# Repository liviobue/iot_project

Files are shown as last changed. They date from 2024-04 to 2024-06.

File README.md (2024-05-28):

# Information about the Project

## Python-Environment
Python 3.12.1

## Project-Structure
### Electronic:
- PCB-Designs
- Output für die Produktion
- Übersicht über die Board-Tests

### NodeRed
- Alle Flows in NodeRed

### Notebooks
- Jupyter Notebooks mit Prototyp-Code
- Jupyter Notebook mit vereinfachtem Code fürs Elektronik-Testing

### Presentation
- Vor-Präsentation
- Präsentation

### Service
- Information zum Service-File, um die Software automatisch beim Boot des Raspberry Pi's zu starten

### src/iot_project
- Code für die verschiedenen Teile der Software

## Get started manually:
### How to install
Execute this from the Repository-Root
```bash
pip install -e .
```

### How to run the sensor measurement only:
Create `.env`-file with `MONGO_URI` containing the connectionstring to your IoT-Database.
Then, run:
```bash
python -m iot_project.main
```

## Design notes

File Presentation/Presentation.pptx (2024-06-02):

## Gruppe 8 Livio Bürgisser – Noémie Käser – Daniela Komenda

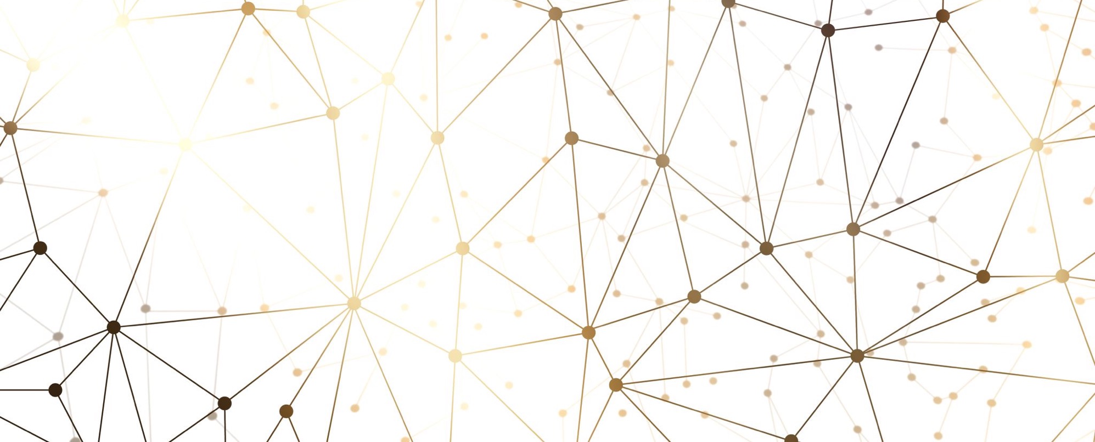
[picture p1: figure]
A web of dots connected

IoT-Projekt

Präsentation
06. Juni 2024

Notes: Herzlich willkommen zu unserer IoT Projekt Präsentation.

## Übersicht

- Problemstellung & Lösung
- Unser Projekt
  - Benutzte Sensoren & Technologien
  - Code
  - Elektronik
  - Dashboard
- Weiterführende Ideen
- Live-Demo

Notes:






Zunächst zum Ablauf der Präsentation.

<klick>
Wir erläutern zunächst die Problemstellung und stellen Euch unsere Lösungsidee vor.

<klick>
Anschliessend werden wir genauer auf unser Projekt eingehen.
Dazu zählt beispielsweise das Vorstellen der benutzten Sensoren und Technologien. Ausserdem werden wir wichtige Code-Überlegungen, sowie unser Vorgehen in Bezug auf die Elektronik vorstellen. Nicht zuletzt präsentieren wir unser Dashboard..

<klick>
Abschliessend werden wir noch einige weiterführende Ideen vorstellen, die leider nicht in scope für dieses Projekt waren.

## Problemstellung

- Luftdichte Räume
- Höhlen
- Tagbau
- Gefahr:
  - Gas-Vergiftung
  - Sauerstoff-Mangel
  - Wird häufig nicht oder zu spät bemerkt

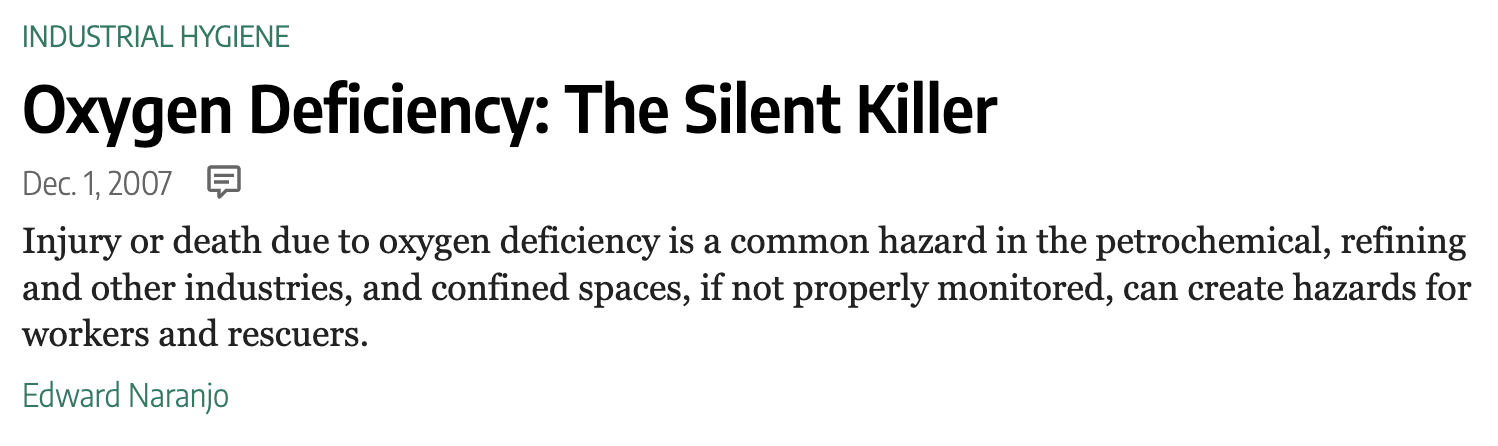
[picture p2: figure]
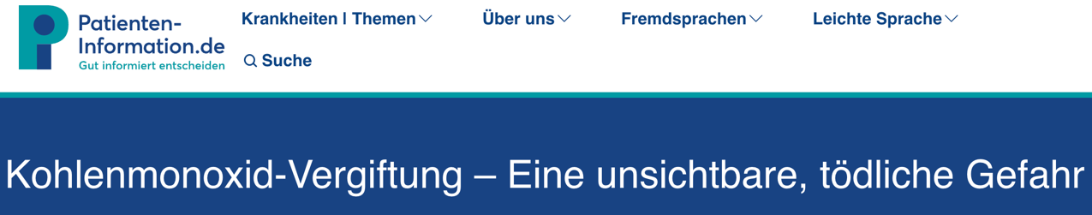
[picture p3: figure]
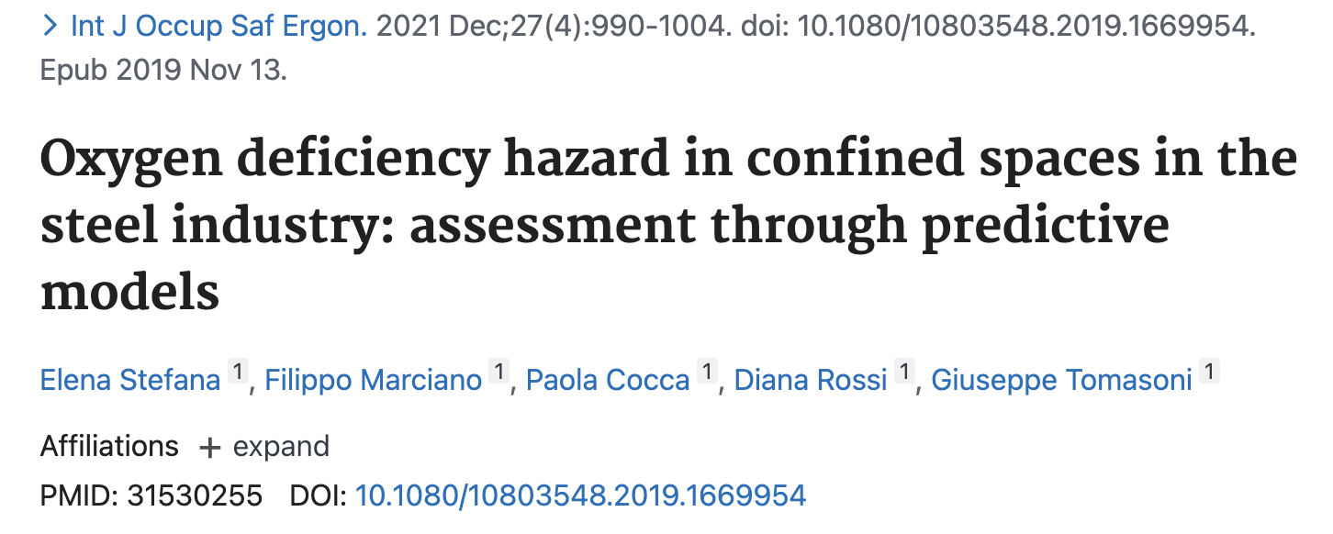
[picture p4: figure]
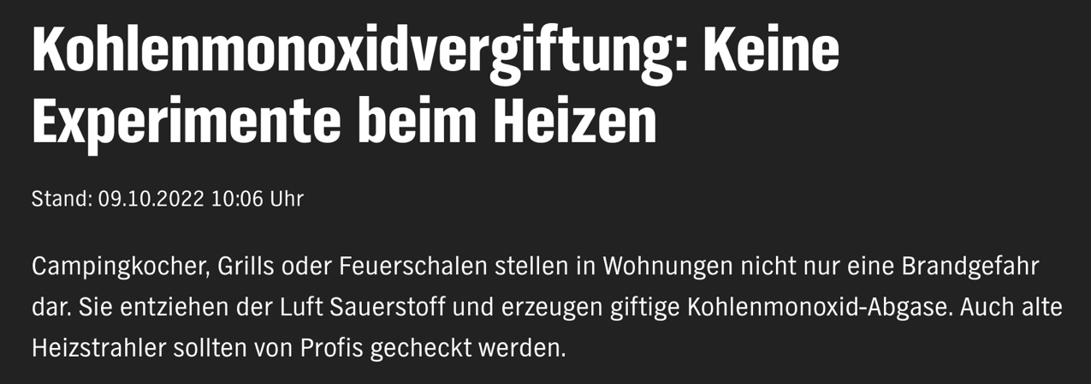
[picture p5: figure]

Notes: Gas kann ein unsichtbarer Feind für uns Menschen sein.
Immer wieder wird in Zeitungen von Unfällen berichtet, in denen Menschen beispielsweise durch zu tiefe Sauerstoff- oder zu hohe Kohlenmonoxid-Werte zu Tode gekommen sind.

<klick>
Insbesondere in luftdichten Räumen, aber beispielsweise auch in Höhlen oder im Tagbau besteht die Gefahr von Gas-Vergiftungen oder einer zu tiefen Sauerstoffkonzentration. Leider werden diese oft erst bemerkt, wenn es bereits zu spät ist und die Menschen das Bewusstsein verloren haben.

## Lösung

- Fahrzeug, das die Umgebung erkundet
- Gas-Konzentrationsmessung im Raum
- Speichern der Gas-Konzentrationen in einer Datenbank für historische Analyse
- Anzeige der Gas-Konzentrationen in einem Dashboard
- Mail bei Gefahr
- Alarm-System bei über- und unterschreiten von Schwellenwerten

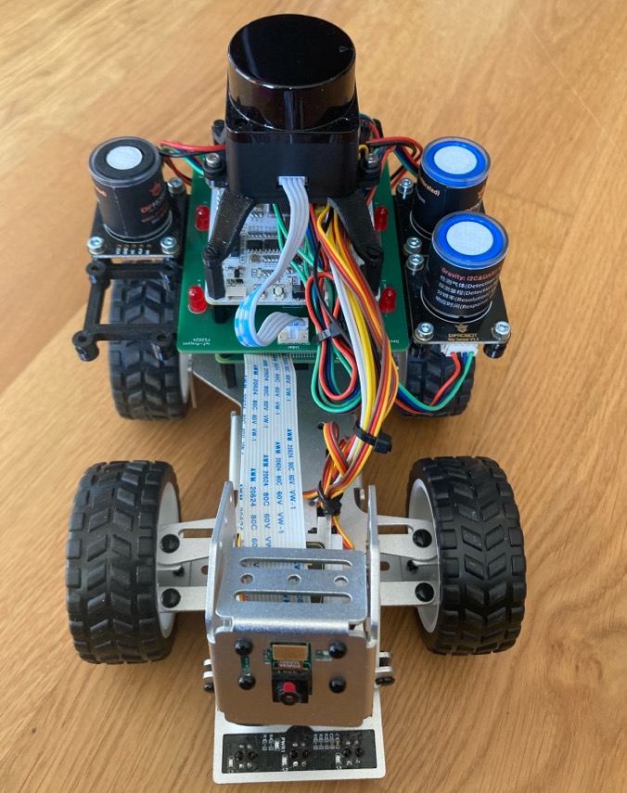
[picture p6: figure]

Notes: Daher stellen wir heute gerne eine mögliche Lösung vor:

<klick>
Unser kleines Fahrzeug kann genutzt werden, um die Umgebung zu erkunden

<klick>
und dabei kontinuierlich die Gas-Konzentration in der näheren Umgebung zu messen.

<klick>
Die Gas-Konzentration wird dann in einer Datenbank gespeichert, so dass man diese auch analysieren könnte, um beispielsweise zu sehen, bei welchen Arbeiten welche Gefahren entstehen könnten.

<klick>
Die Gas-Konzentration wird aber auch in einem Dashboard angezeigt, so dass sie nahezu real-time überwacht werden kann

<klick>
und bei einer Gefahr, wird eine Mail an die Mitarbeitenden geschickt.

<klick>
Das Fahrzeug selber verfügt ebenfalls über ein Alarmsystem, so dass die jeweiligen LED rot leuchten, wenn der betreffende Sensor den definierten Schwellenwert über- beziehungsweise unterschreitet. Ausserdem erzeugt ein Buzzer auch ein akustisches Signal.

## Benutzte Sensoren / Technologie

- Raspberry Pi
- PiCar von Sunfounder
- Gas-Sensoren von DFRobot (vorkalibriert)
  - NH3
  - CO
  - O2
- NodeRed
- Lidar von LDRobot

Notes: Um unsere Lösungen umzusetzen haben wir folgende Sensoren und Technologien genutzt.

<klick>
Zum einen läuft die Software-Lösung auf einem Raspberry Pi.

<klick>
Dieses haben wir an den PiCar von Sunfounder angeschlossen, mit dem wir die Umgebung erkunden können.

<klick>
Als Gas-Sensoren nutzen wir vorkalibrierte Sensoren von DFRobot.

<klick>
Wir haben uns für die Demonstration für Ammoniak-, Kohlenmonoxid- und Sauerstoff-Messung entschieden. DFRobot hat aber noch weitere Sensoren und man kann diese recht einfach ersetzen. Auch in der Software müssten nur wenige Anpassungen vorgenommen werden.

<klick>
Für das Dashboard verwenden wir NodeRed, da wir diese Technologie im Rahmen des Moduls kennengelernt haben und es uns überzeugt hat.

<klick>
Für die Orientierung im Raum haben wir noch einen 2D-Lidar von LDRobot in die Lösung eingebaut, aber leider war die sinnvolle Nutzung von diesem dann Out-of-Scope.

## High-Level Übersicht

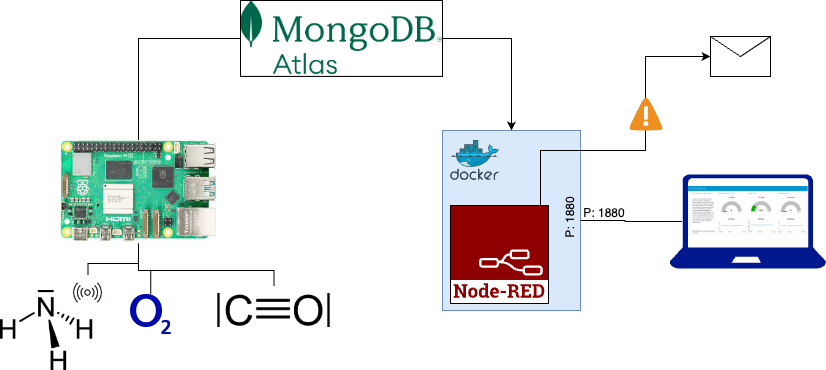
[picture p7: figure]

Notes: Prototypisieren mit Notebooks, nachher umschrieben zur Python-Library.

Python Scripts werden mit Systemd Service auf Raspberry Pi gestartet und der die Software mit Sensor-Messung & PiCar-Steuerung automatisch laufen lässt.

## Code – Externe Libraries

- Sensor-Library von DFRobot
  - Problem: viele Fehler
  - Folge: bricht immer wieder ab
  - Lösung: Library clonen und umschreiben
- Controller PiCar von Sunfounder
  - SunFounder-Library
  - Umschreiben von einigen Funktionen

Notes: Nun erläutern wir gerne noch die wichtigsten Überlegungen zum Software-Code.

<klick>
Um die Sensoren zu nutzen, braucht es die Library von DFRobot. Leider haben wir feststellen müssen, dass es extrem viele Fehler gibt, die das Programm dann abbrechen lassen. Da es sich bei den Sensoren um Hardware handelt, ist es möglich, dass einige Messungen nicht immer funktionieren. Diese sollten dann einfach übersprungen werden und nicht das ganze Programm abbrechen. Daher haben wir uns entschieden, die Library zu klonen und für unser Projekt anzupassen. So konnten wir nur den Teil aus der Library rausnehmen, den wir gebraucht haben.

<klick>
Für den PiCar haben wir die Library von SunFounder verwendet und dort beim picarx-controller einige Funktionen angepasst, so dass der PiCar beispielsweise vor einer Wand langsamer wird, damit man nicht mit vollem Tempo hineinfährt.

## Code – Datenverarbeitung

- Measurement-Loop:
  - Messung im Measurement-Intervall von 0.1 Sekunden
  - Alert-Überprüfung
  - Aggregation der Werte über 0.5 Sekunden (Min, Max, Avg)
  - MongoDB
    - Datenbereinigung?

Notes: Für die Datenverarbeitung haben wir einen Measurement-Loop erstellt, der alle 0.1 Sekunden die Sensoren ansteuert und die Gas-Konzetration misst.

Die Werte werden nach diesem Measurement-Intervall überprüft und mit den festgelegten Alert-Level verglichen.


Die gelesenen Daten werden in einer Liste gespeichert und alle 0.5 Sekunden aggregiert. Dabei wird der Timestamp übergeben, sowie der Minimal- und Maximal- und der Durchschnittswert berechnet.

Die aggregierten Daten werden dann in die MongoDB geladen.

Für die Zukunft müsste man sich allenfalls noch ein Handling überlegen, wie man mit älteren Daten umgeht. Allenfalls könnte man Tages-Durchschnitte berechnen und in eine separate Collection speichern und alte Raw-Daten dann löschen, damit die Datenbank nicht überflutet wird.

## Code – Alarm

- AlertManager:
  - Setup-Verwaltung
  - Überprüfung ob Schwellenwerte über- beziehungsweise unterschritten wurden
- Modi:

| NORMAL | ALERT | ACKNOWLEDGE
Grüne LED | Leuchtend | Aus | Aus
Rote LED(s) | Aus | Blinkend | Leuchtend
Buzzer | Aus | An | Aus

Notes: Ein wichtiger Teil des Codes ist auch der AlertManager. Dieser verwaltet den Setup, wo die Adressierung der Elektronik-Komponenten festgelegt wird. Ausserdem werden im AlertManager die Schwellenwerte definiert und überprüft, ob sie über- beziehungsweise unterschritten werden.

<klick>
Für den Alarm haben wir 3 unterschiedliche Modi definiert.

Der erste Modus ist der normale Modus. Dabei leuchtet die grüne LED und die roten LEDs und der Buzzer sind ausgeschaltet. So weiss man, dass das Gerät an ist und die Software läuft.
Bei einem Alarm, wird die grüne LED ausgeschaltet und die betreffenden roten LEDs blinken. Auch der Buzzer ist dann an. Bei einem Alarm hat man die Möglichkeit, den Switch zu drücken, so dass der Zustand in den Acknowledge-Modus wechselt. In diesem ist die grüne LED immer noch aus und die betreffenden roten LEDs leuchten statt zu blinken. Ausserdem ist der Buzzer wieder ausgeschaltet. Alle 0.4 Sekunden wird überprüft, ob sich die Gas-Konzentration immer noch im kritischen Bereich befindet. Falls nicht, wird wieder auf den Normal-Modus zurückgesetzt.

## Elektronik – Breadboard-Prototyping

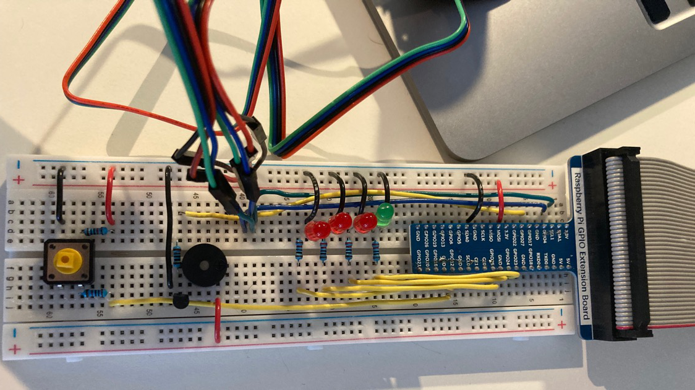
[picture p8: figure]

- 1. Prototyp nur mit O2-Sensor
- 2. Prototyp mit NH3-, CO- und O2-Sensor, aber ohne Buzzer und Switch
- 3. Prototyp mit allen Sensoren, inklusive Buzzer und Switch

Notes: Nun kommen wir zur Elektronik.
Ursprünglich haben wir die Prototypisierung mit einem Breadboard gemacht.

<klick>
In der ersten Iteration haben wir nur einen Sensor angeschlossen und auch dementsprechend nur 1 rotes und 1 grünes LED.

<klick>
In der 2. Iteration haben wir dann alle drei Sensoren genutzt und überprüft, ob die LEDs einzeln leuchten aber ob es auch möglich ist, dass mehrere gleichzeitig Alarm anzeigen.

<klick>
In der 3. und letzten Iteration haben wir dann alle Sensoren und auch den Buzzer und den Switch angeschlossen.

Doch obwohl wir versucht haben, die Kabel so kurz wie möglich zu halten, waren wir mit dieser klobigen Lösung unzufrieden. Daher haben wir uns entschieden, unsere eigene Platine zu designen.

## Elektronik – Platinen-Design

- Schwierigkeit
  - Platine soll Erweiterung mit PiCar und Lidar ermöglichen
  - Nicht alle Pins können genutzt werden
  - Theoretisch können 4 Sensoren parallel geschaltet werden
- Lösung
  - Dokumentation von PiCar, welche Pins genutzt werden
  - Dokumentation von Lidar, welche Pins genutzt werden
- Umsetzung
  - Pins werden entsprechend angeschrieben
  - Platz für 4 Sensoren schaffen

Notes: Die Schwierigkeit war, dass wir eigentlich nur die 3 Gas-Sensoren, nicht aber den Lidar und den PiCar auf dem Board testen konnten. Daher wussten wir, dass wir nicht alle Pins nutzen dürfen, da wir die Erweiterung mit dem PiCar und dem Lidar unbedingt offenbehalten wollten. Ausserdem kann man theoretisch 4 Sensoren von DFRobot parallel nutzen, daher wollten wir auch einen 4. Sensor im Elektronik-Design einbinden.

<klick>
Die Lösung für die Schwierigkeiten war, dass wir die Dokumentation vom PiCar und vom Lidar nutzen mussten, um zu erfahren, welche Pins gebraucht werden. Glücklicherweise gab es beim PiCar und beim Lidar keine Überschneidungen.

<klick>
Als wir die Pins auf dem Design entsprechend angeschrieben und blockiert hatten, haben wir für die restlichen 4 Sensoren die Pins verteilt

## Elektronik – Platinen-Design mit KiCAD

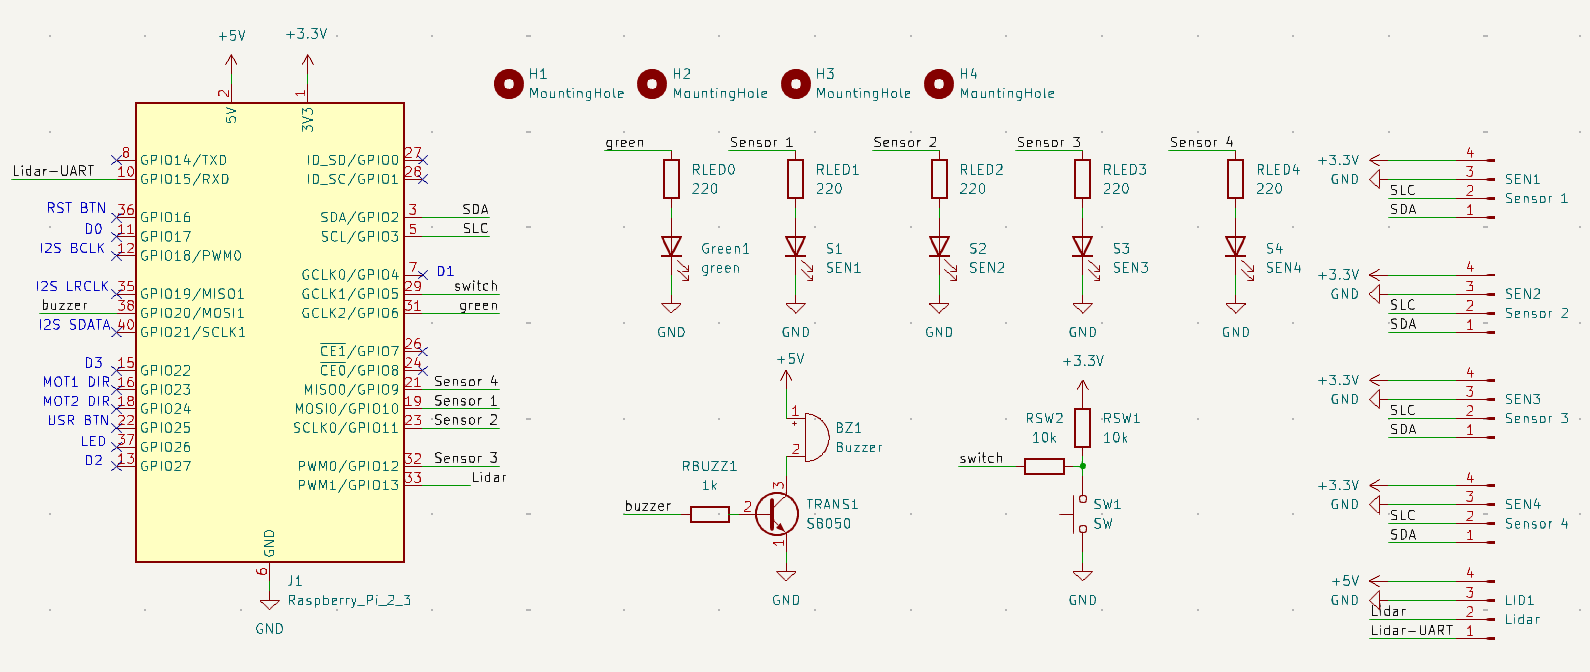
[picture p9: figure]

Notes: Dies hat dann so ausgesehen.
Das Design wurde mit KiCAD erstellt. Im Schemata-Editor kann man alle Komponenten zeichnen und dem Board zuordnen. Verbindungen werden dann erst im nächsten Schritt gemacht.

## Elektronik – Platinen-Design

- Verbindungen
  - 2 Layer, da günstig und das Design genügend einfach
- Herausforderung
  - Komponenten-Footprint muss stimmen
  - Holes müssen am korrekten Ort sein
  - Pins müssen am korrekten Ort sein
  - Komponenten, die höher sind, dürfen nicht mit dem Board vom PiCar kollidieren

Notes: Nachdem das Design fertiggestellt war, konnte man im PCB-Editor das eigentliche Design erstellen. Wir haben beschlossen, dass wir uns auf 2 Layer beschränken, da wir grundsätzlich einen einfachen Use-Case haben und 2 Layer deutlich günstiger sind.

<klick>
Die Herausforderung war, dass wir überprüfen mussten, dass die gewählten Footprints stimmen, damit wir die richtige Grösse der Komponenten haben. Ausserdem mussten wir genau messen, um die Schraub-Löcher und die Pins am richtigen Ort zu haben.
Da wir das Board vom PiCar auf unser Design raufstecken wollten, mussten wir auch sicherstellen, dass höhere Komponenten, wie beispielsweise der Transistor oder der Buzzer nicht mit der Elektronik des PiCar-Boards kollidieren.

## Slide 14

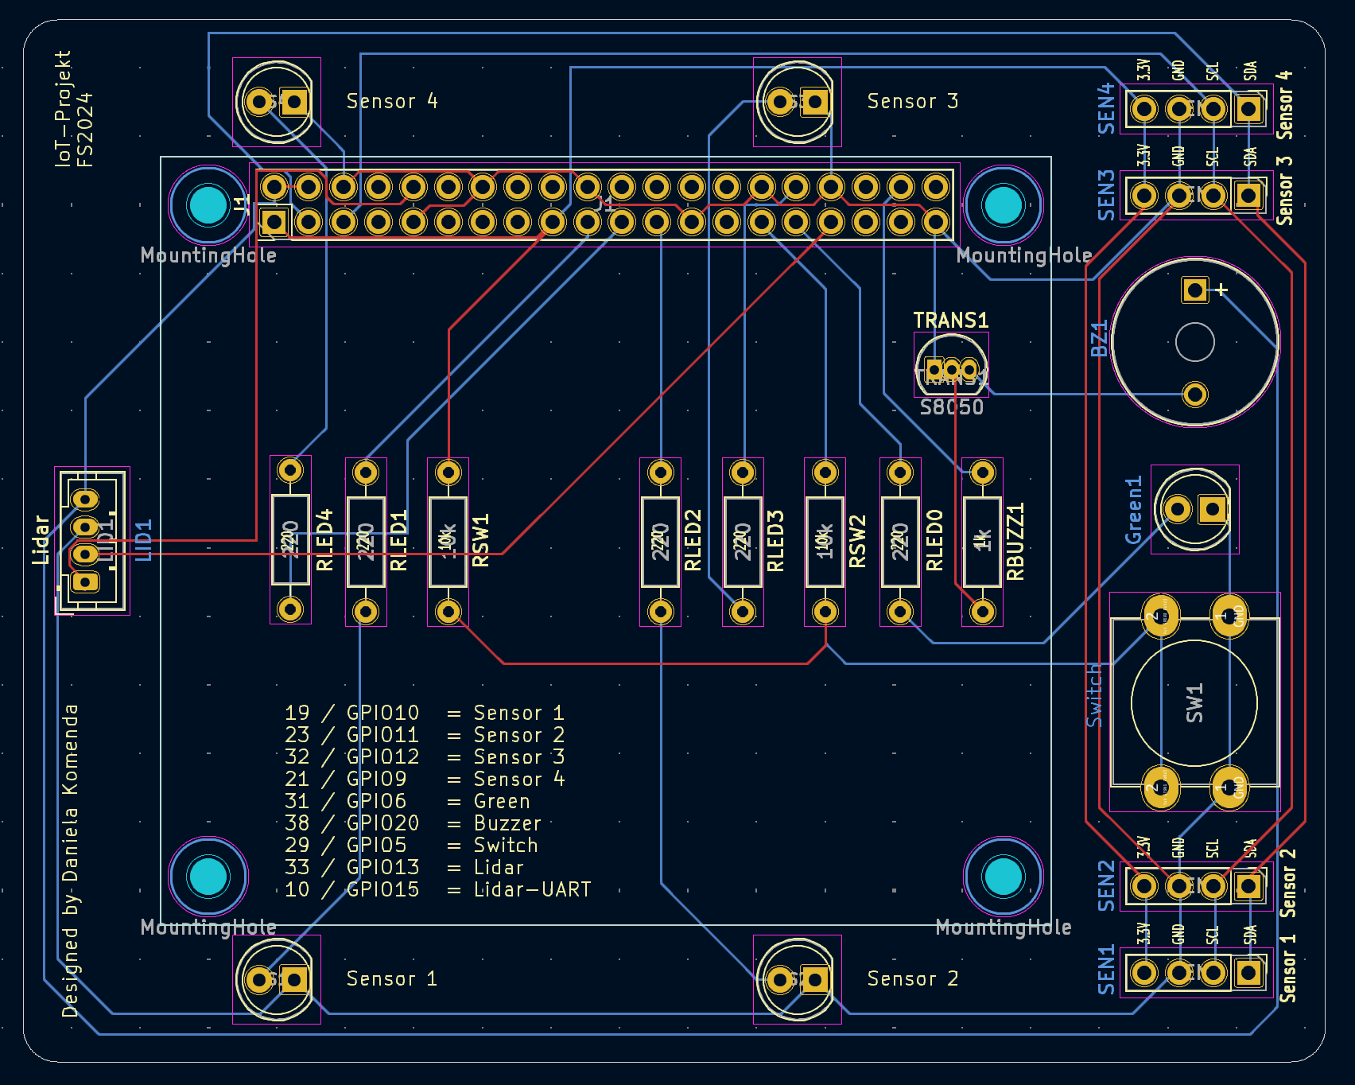
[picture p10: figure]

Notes: Die Lösung sah am Schluss so aus.

## Elektronik – Produktion durch PCB-Way

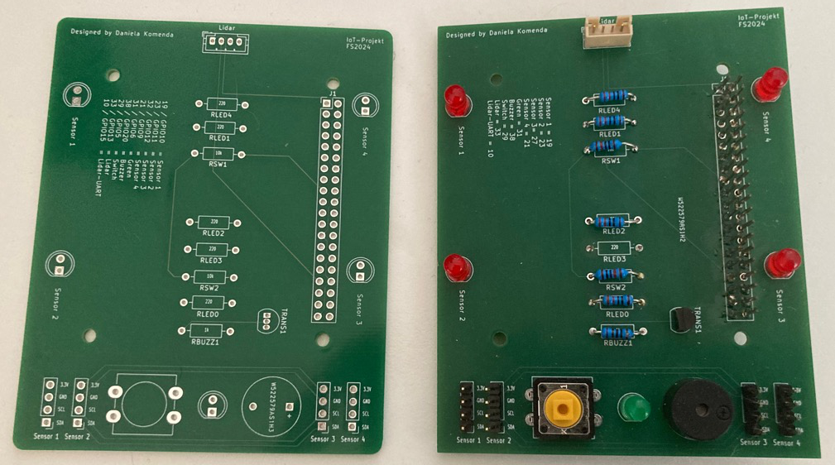
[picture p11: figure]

- Produktion von 10 PCB durch PCB-Way in China
- Bestellung der Komponenten bei DigiKey
- Selbstständiges Löten der Komponenten

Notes: Als das Design dann fertig war, haben wir uns informiert, wo man es bestellen kann.

<klick>
Anschliessend haben wir 10 PCBs bei PCB-Way in China bestellt.

<klick>
Die Elektronik-Komponenten haben wir bei DigiKey bestellt.

<klick>
Und anschliessend auf die Boards gelötet.

## Elektronik – Löten

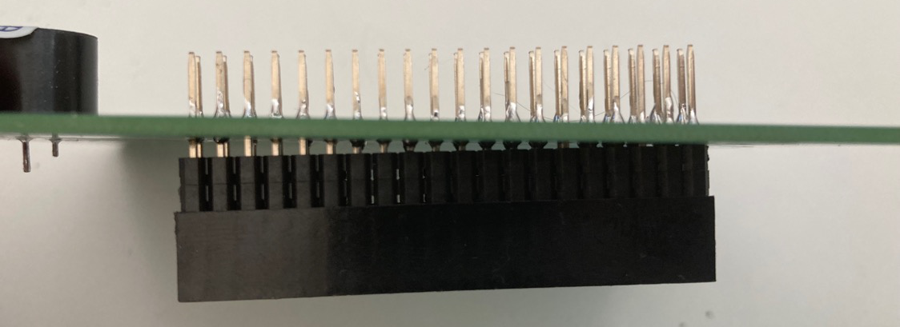
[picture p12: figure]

- Herausforderung 1:
  - Komponenten sollen nicht schräg gelötet sein
- Lösung 1:
  - Tape
- Herausforderung 2:
  - Löt-Zinn mit Blei
- Lösung 2:
  - siehe Bild

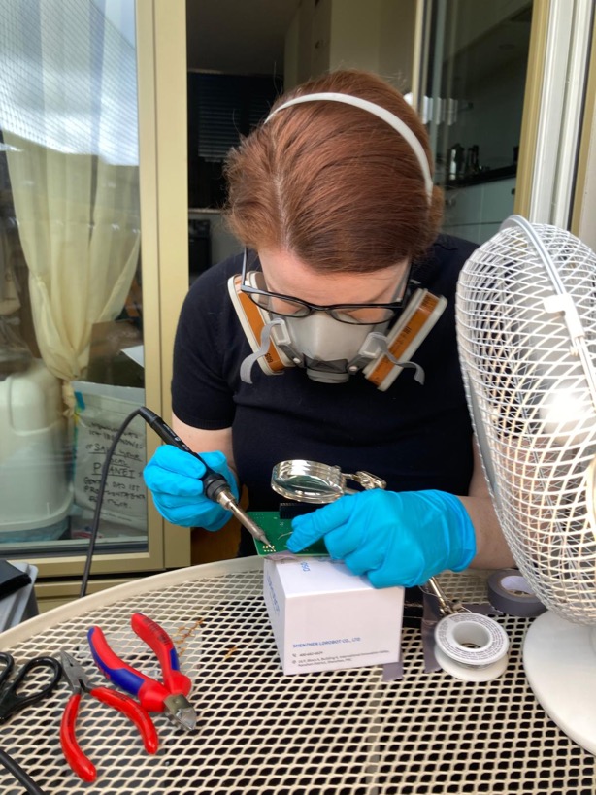
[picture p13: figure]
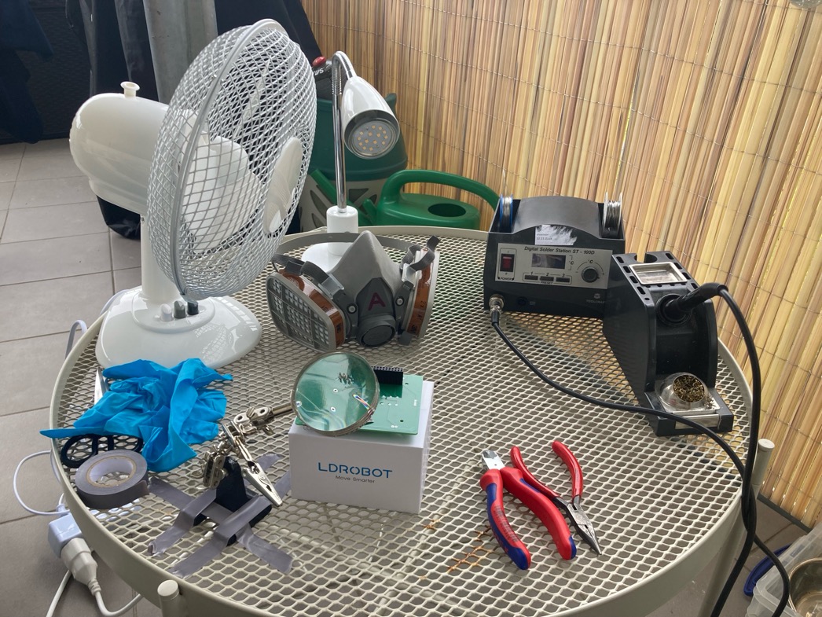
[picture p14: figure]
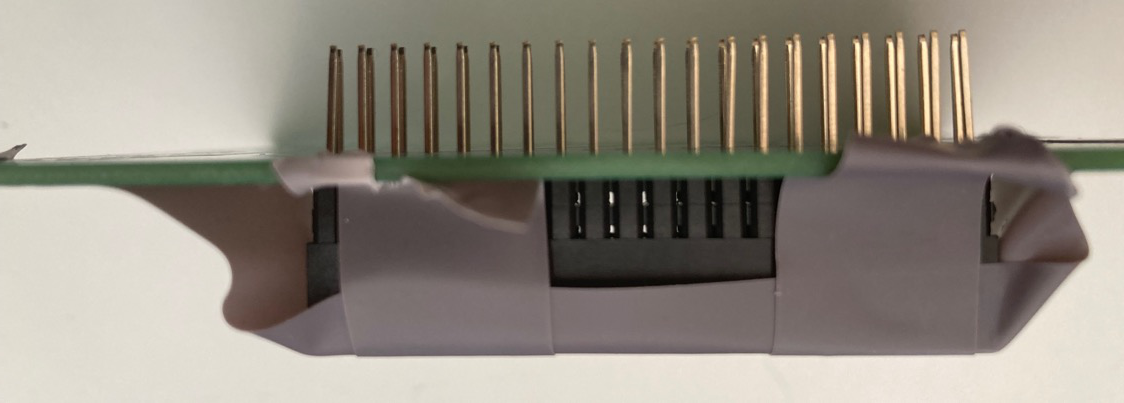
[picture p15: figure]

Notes: Beim Löten kamen wir an folgende Herausforderungen:

<klick>
Beim ersten Lötversuch stellten wir fest, dass die Komponenten durchaus auch schräg gelötet werden können, wie man auf dem Bild sieht.

<klick>
Als Lösung dafür haben wir Tape genutzt, um die Komponenten zu befestigen.

<klick>
Die zweite Herausforderung war, dass wir hauptsächlich mit bleihaltigem Löt-Zinn gearbeitet haben, da dieser insbesondere für schwierigere Lötstellen, wie die Pins oder die Löt-Stellen des Transistors geeigneter war als bleifreier Löt-Zinn. Da er aber giftig ist, mussten wir uns eine Lösung überlegen.

<klick>
Daher wurde auf meinem Balkon eine gut durchlüftete Löt-Station eingerichtet und als zusätzlicher Schutz noch eine Brille und eine Atemschutz-Maske verwendet.

## Dashboard mit Node Red

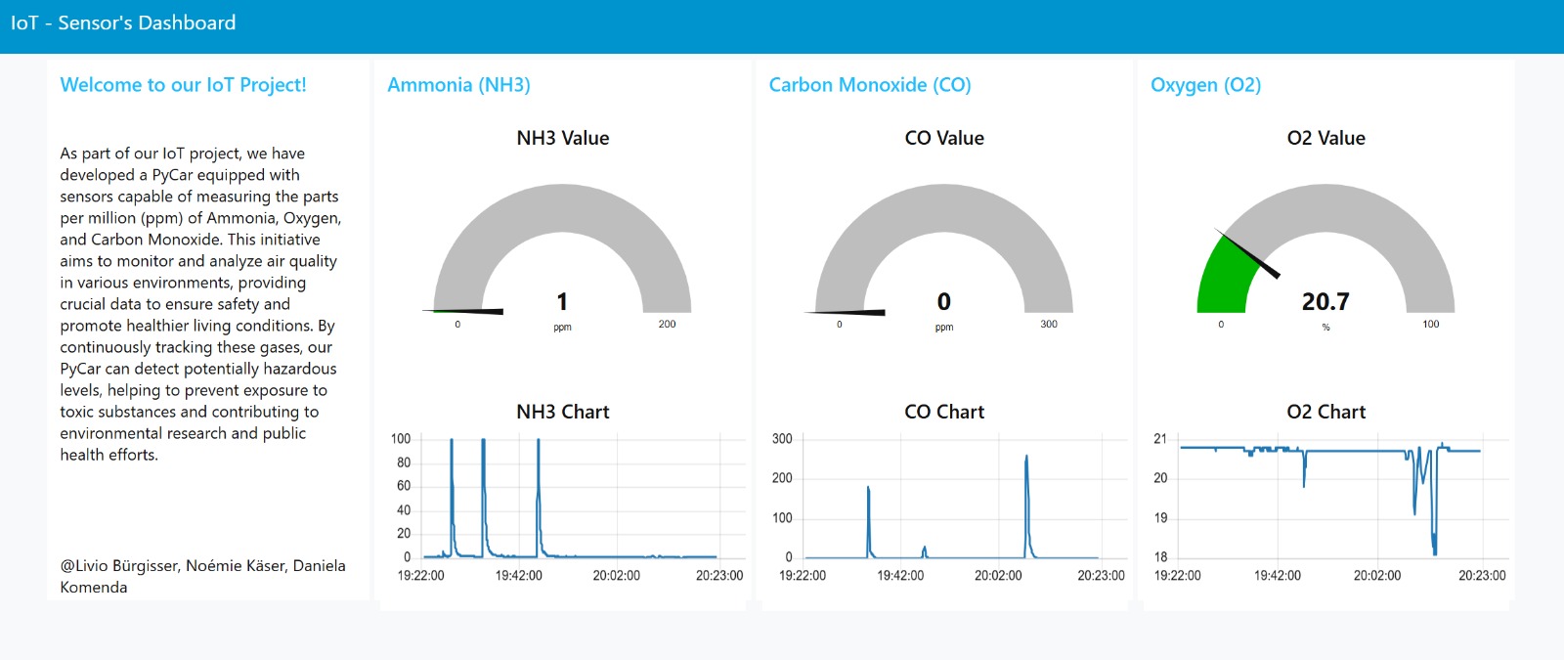
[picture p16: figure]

## Node ReD FLOW

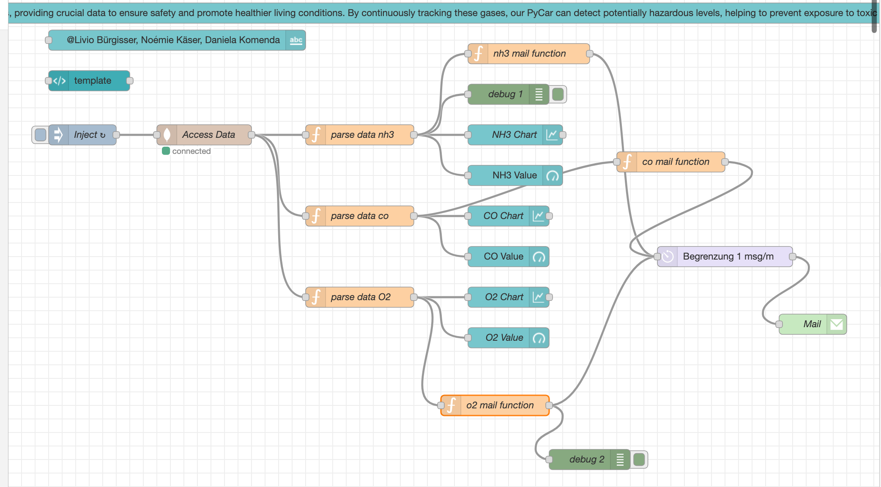
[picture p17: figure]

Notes: Hier flow für dashboard gerade verbunden mit einem mail, welches bei gefahr versendet wird.

## Weiterführende Ideen

- Raum-Erfassung mit Lidar und PiCar-Kamera
- Finden des Gas-Lecks
- Energie-Management des Fahrzeugs
- Daten-Management

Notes: Nun kommen wir noch zu den Ideen, die leider Out-of-Scope waren.

<klick>
Zum einen hätte man den PiCar selbstständig den Raum erkunden lassen können. Dazu hätte man den Lidar-Sensor für die Raum-Erfassung nutzen können, damit der PiCar gezielter den Raum erkundet.

<klick>
Ausserdem wäre es cool gewesen, wenn der PiCar bei einer auffälligen Gas-Konzentration, versucht hätte, herauszufinden, woher das Gas kommt und sich dann immer näher zum Gas-Leck bewegt hätte.

<klick>
Ausserdem hält der Akku des PiCars nicht sehr lange, daher wäre es sicherlich noch sinnvoll, sich in Zukunft Gedanken zum Energie-Management des Fahrzeugs zu machen. Allenfalls könnte man noch weitere Batterien anschliessen oder allenfalls einen Arduino statt eines Raspberry Pis verwenden.

<klick>
Das Daten-Management in der DB haben wir ja bereits angesprochen. Es würde auch dort noch weitere Optimierungen geben.

## Live-Demo

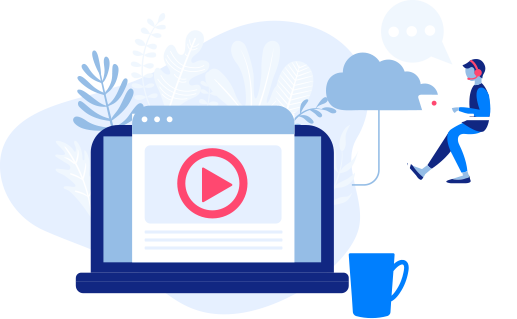
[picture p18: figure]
Request a demo - Comsys

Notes: Damit sind wir am Ende unserer Präsentation und würden nun gerne eine Live-Demo unserer IoT-Lösung demonstrieren.
Wir haben dafür ein Video aufgenommen, dass den gesamten Scope zeigt.
Für die Vorführung im Klassenzimmer haben wir uns überlegt, dass wir einfach kurz die Fahrweise, sowie den O2-Sensor und unser Dashboard demonstrieren.
Wir hätten aber auch Räucherstäbchen und Ammoniak dabei, würden aber empfehlen, dass wir dieses nicht im Unterrichtraum selber demonstrieren, da es für die nächste Gruppe und Euch als Dozierende eventuell unangenehm werden könnte.

## Github-Repo

https://github.com/liviobue/iot_project

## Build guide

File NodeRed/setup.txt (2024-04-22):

sudo apt-get update
sudo apt-get full-upgrade

sudo apt install sense-hat 
sudo reboot

sudo apt install python3-paho-mqtt

# Prüfen ob installiert
node --version
npm --version

bash <(curl -sL https://raw.githubusercontent.com/node-red/linux-installers/master/deb/update-nodejs-and-nodered)

sudo apt install python3-wget

# start, stop node red
node-red-start
node-red-stop

# mosquitto
sudo apt install mosquitto
sudo apt install mosquitto-clients

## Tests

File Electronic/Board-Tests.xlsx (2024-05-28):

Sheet: Daniela
Daniela | Test 1 small | Test 2 big | Nachtest | TEST
LED Green | pass | pass | - | OK
LED 1 | pass | - | - | OK
LED 2 | pass | - | - | OK
LED 3 | pass | - | - | OK
LED 4 | pass | - | - | OK
Switch | pass | - | - | OK
Buzzer | pass | - | - | OK
Sensor 1 | pass | pass | - | OK
Sensor 2 | pass | pass | - | OK
Sensor 3 | pass | pass | - | OK
Sensor 4 | pass | - | - | OK
Lidar | - | pass | - | OK
PiCar | - | pass | - | OK

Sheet: Noémie
Noémie | Test 1 small | Test 2 big | Nachtest | TEST
LED Green | pass | pass | pass | OK
LED 1 | pass | - | - | OK
LED 2 | pass | - | - | OK
LED 3 | pass | - | - | OK
LED 4 | pass | - | - | OK
Switch | pass | - | - | OK
Buzzer |  |  | pass | OK
Sensor 1 | pass | pass | pass | OK
Sensor 2 | pass | pass | - | OK
Sensor 3 | pass | pass | - | OK
Sensor 4 | pass | - | - | OK
Lidar | - | pass | - | OK
PiCar | - | pass | - | OK

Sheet: Livio
Livio | Test 1 small | Test 2 big | Nachtest | TEST
LED Green | pass | pass | pass | OK
LED 1 | pass | - | - | OK
LED 2 | pass | - | - | OK
LED 3 | pass | - | - | OK
LED 4 | pass | - | - | OK
Switch | pass | - | - | OK
Buzzer | fail | - | pass | OK
Sensor 1 | pass | pass | - | OK
Sensor 2 | pass | pass | - | OK
Sensor 3 | fail | fail | pass | OK
Sensor 4 | fail | - | pass | OK
Lidar | - | pass | - | OK
PiCar | - | pass | - | OK

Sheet: Christian
Christian | Test 1 small | Test 2 big | Nachtest | TEST
LED Green | pass | pass | pass | OK
LED 1 | pass | - | - | OK
LED 2 | pass | - | - | OK
LED 3 | pass | - | - | OK
LED 4 | pass | - | - | OK
Switch | pass | - | - | OK
Buzzer | pass | - | - | OK
Sensor 1 | pass | pass | - | OK
Sensor 2 | fail | pass | - | OK
Sensor 3 | pass | pass | - | OK
Sensor 4 | fail | - | pass | OK
Lidar | - | pass | - | OK
PiCar | - | pass | - | OK

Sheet: Peter
Peter | Test 1 small | Test 2 big | Nachtest | TEST
LED Green | pass | pass | - | OK
LED 1 | pass | - | - | OK
LED 2 | pass | - | - | OK
LED 3 | pass | - | - | OK
LED 4 | pass | - | - | OK
Switch | pass | - | - | OK
Buzzer | pass | - | - | OK
Sensor 1 | pass | pass | - | OK
Sensor 2 | pass | pass | - | OK
Sensor 3 | pass | pass | - | OK
Sensor 4 | pass | - | - | OK
Lidar | - | pass | - | OK
PiCar | - | pass | - | OK

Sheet: Mario
Mario | Test 1 small | Test 2 big | Nachtest | TEST
LED Green | pass | pass | - | OK
LED 1 | pass | - | - | OK
LED 2 | pass | - | - | OK
LED 3 | pass | - | - | OK
LED 4 | pass | - | - | OK
Switch | pass | - | - | OK
Buzzer | pass | - | - | OK
Sensor 1 | pass | pass | - | OK
Sensor 2 | pass | pass | - | OK
Sensor 3 | pass | pass | - | OK
Sensor 4 | pass | - | - | OK
Lidar | - | pass | - | OK
PiCar | - | pass | - | OK

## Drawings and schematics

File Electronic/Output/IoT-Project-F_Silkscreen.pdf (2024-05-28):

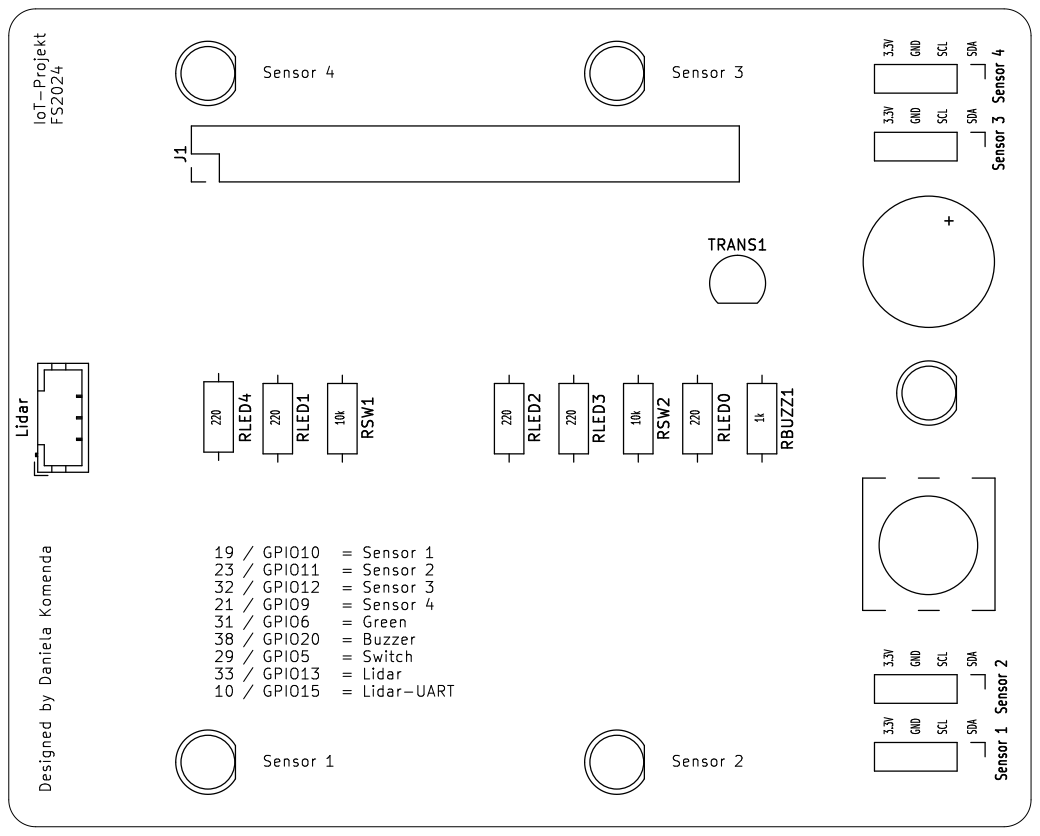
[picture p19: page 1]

SCL SCL 10k SCL 3.3V 1k SDA 3.3V IoT-Projekt FS2024 GND Sensor 1 220 220 SDA Sensor 3 SDA Designed by Daniela Komenda 3.3V 220 10k GND SDA

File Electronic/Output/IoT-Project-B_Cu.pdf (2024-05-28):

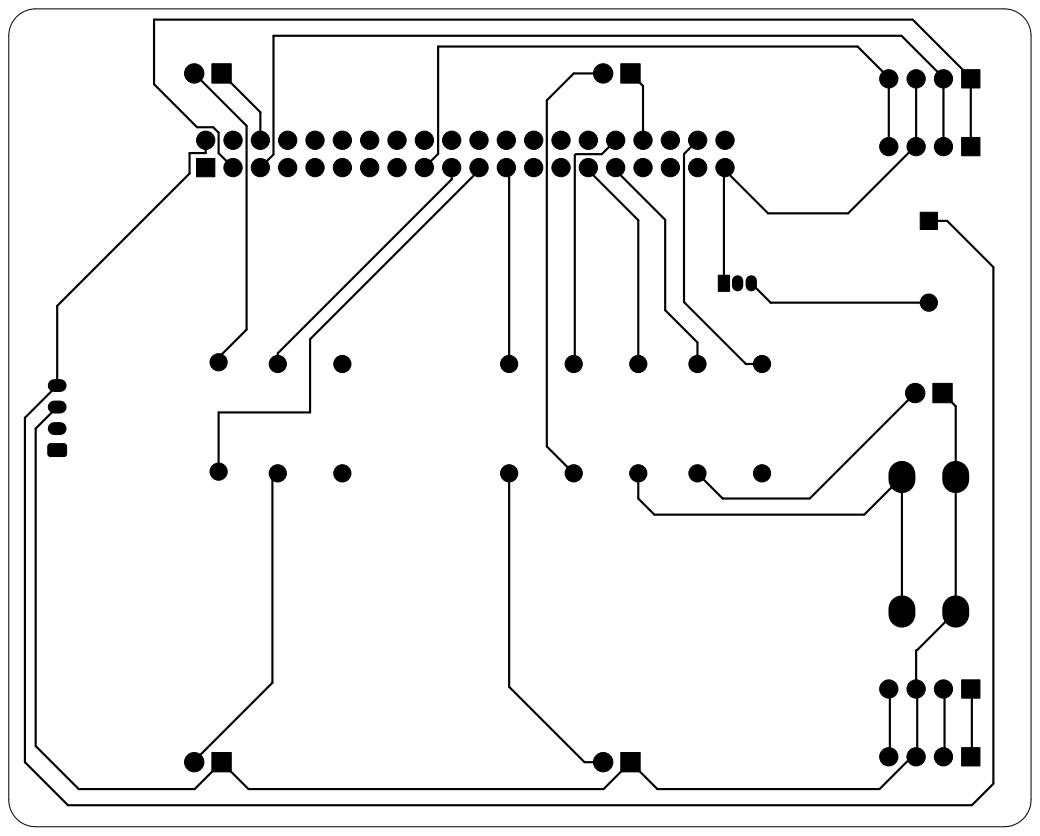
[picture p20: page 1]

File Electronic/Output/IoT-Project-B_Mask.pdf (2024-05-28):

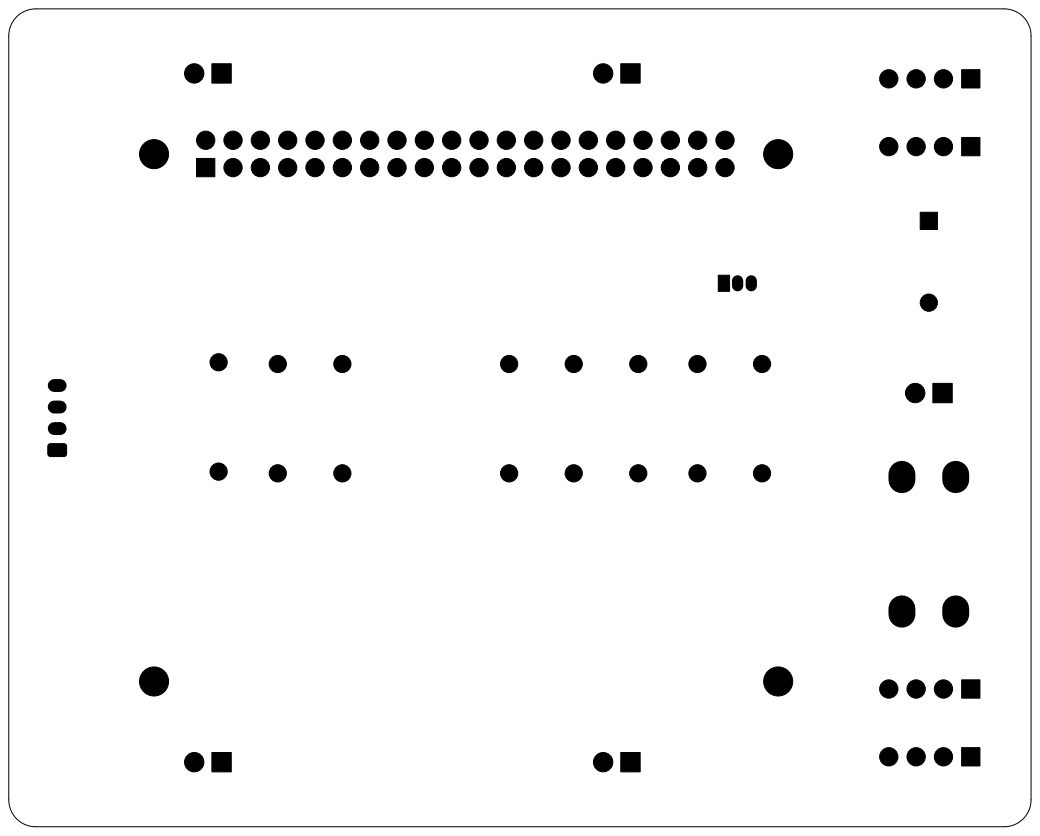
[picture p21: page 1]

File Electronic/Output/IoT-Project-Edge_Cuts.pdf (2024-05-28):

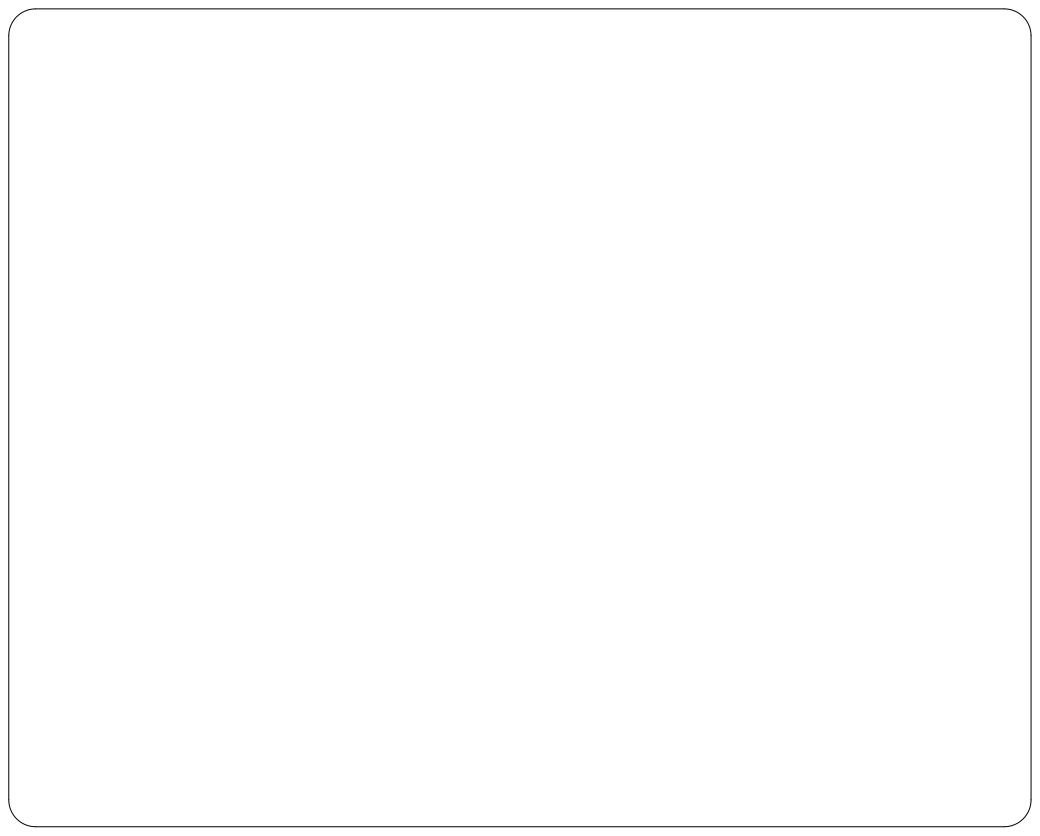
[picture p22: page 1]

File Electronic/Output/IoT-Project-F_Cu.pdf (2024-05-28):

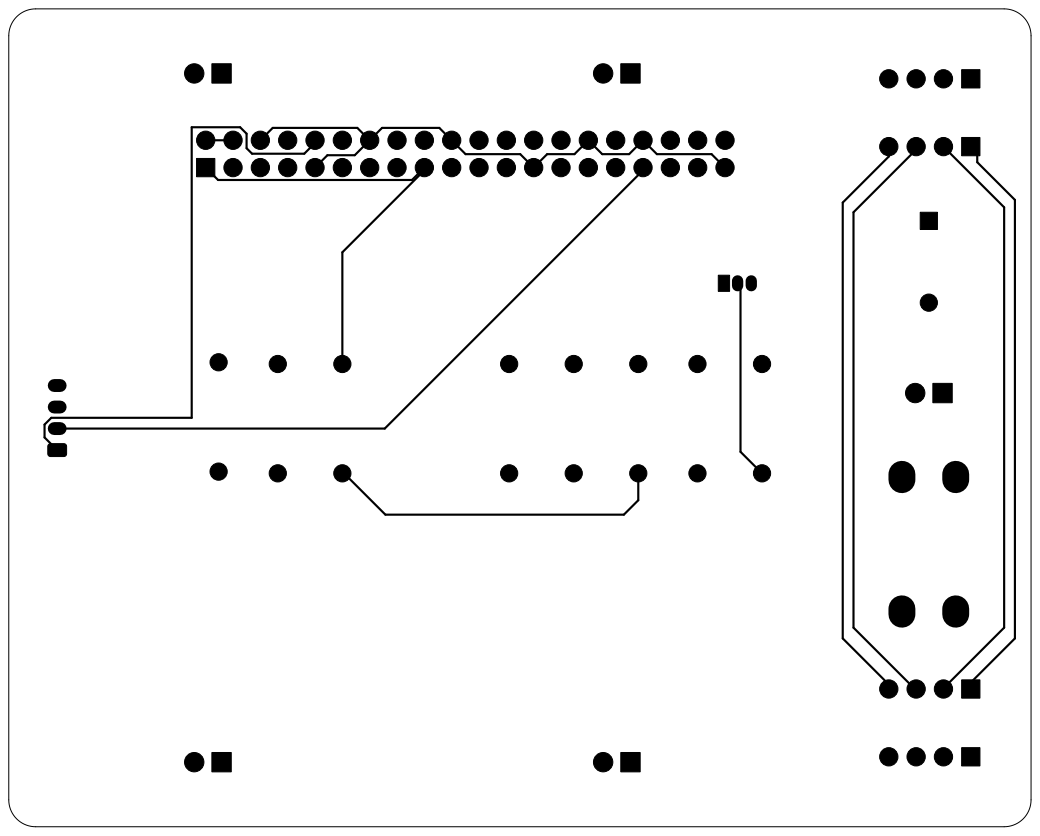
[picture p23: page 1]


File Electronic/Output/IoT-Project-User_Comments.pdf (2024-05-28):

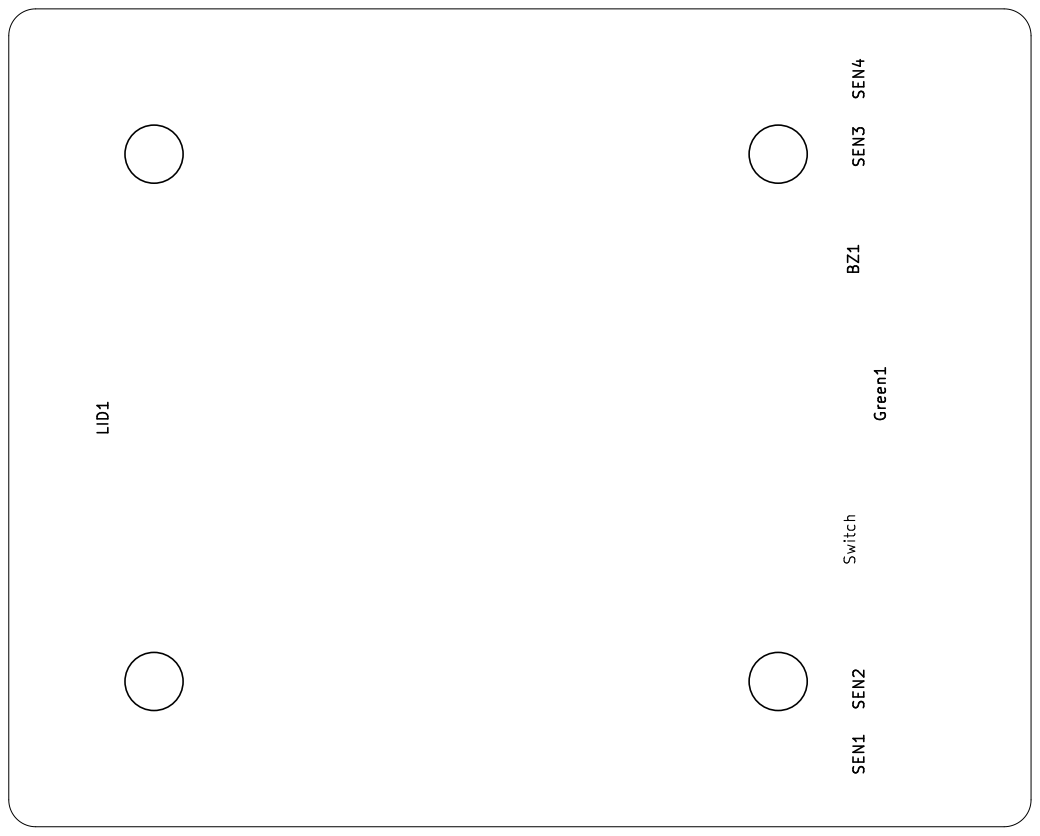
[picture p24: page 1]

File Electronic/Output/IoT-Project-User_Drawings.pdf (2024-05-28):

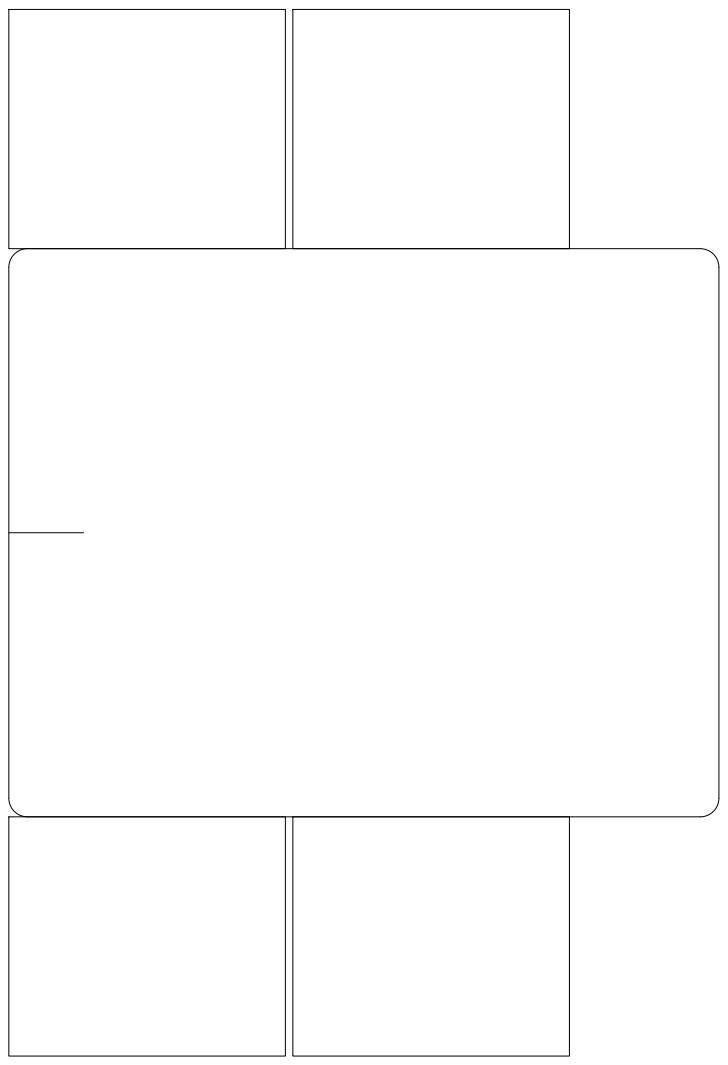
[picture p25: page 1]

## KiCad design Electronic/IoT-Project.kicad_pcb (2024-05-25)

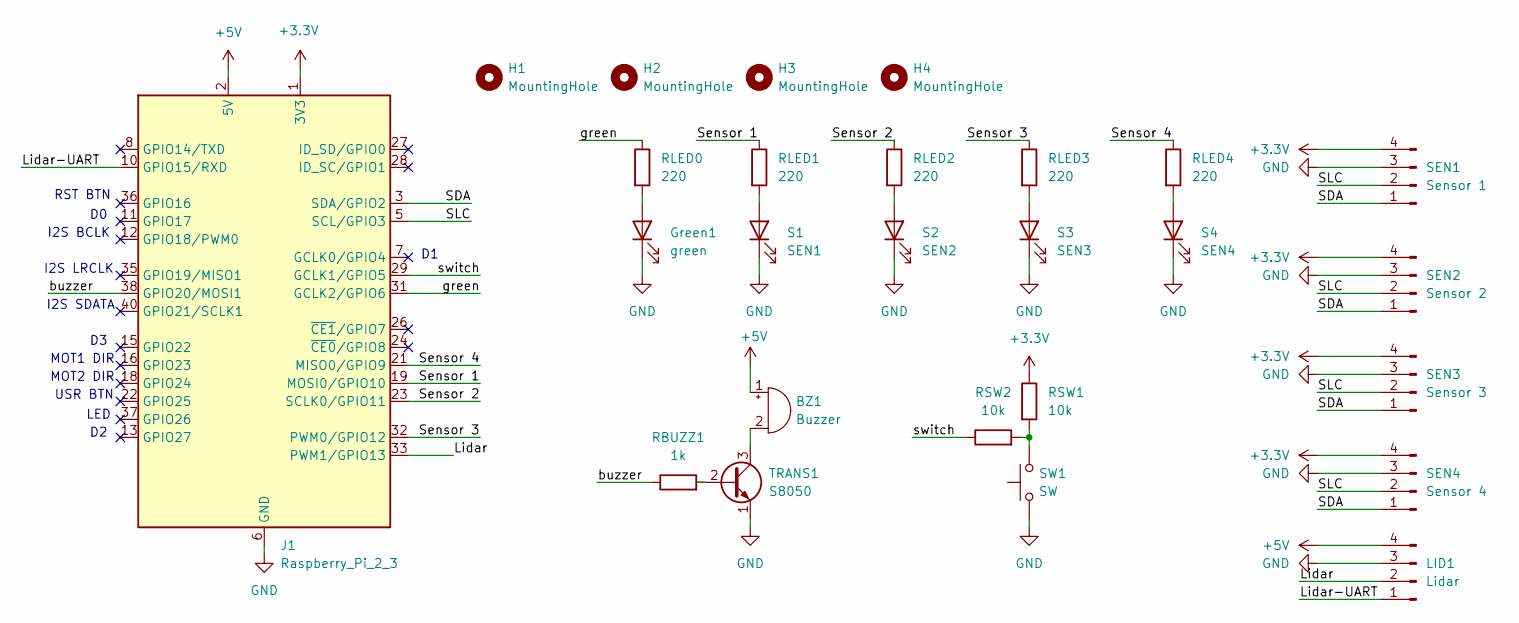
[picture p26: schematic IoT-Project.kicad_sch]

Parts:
BZ1: Buzzer; MagneticBuzzer_ProSignal_ABI-010-RC
Green1: green; LED_D5.0mm
H1, H2, H3, H4: MountingHole; MountingHole_2.7mm_M2.5
J1: Raspberry_Pi_2_3; PinHeader_2x20_P2.54mm_Vertical
LID1: Lidar; JST_PH_B4B-PH-K_1x04_P2.00mm_Vertical
RBUZZ1: 1k; R_Axial_DIN0207_L6.3mm_D2.5mm_P10.16mm_Horizontal
RLED0, RLED1, RLED2, RLED3, RLED4: 220; R_Axial_DIN0207_L6.3mm_D2.5mm_P10.16mm_Horizontal
RSW1, RSW2: 10k; R_Axial_DIN0207_L6.3mm_D2.5mm_P10.16mm_Horizontal
S1: SEN1; LED_D5.0mm
S2: SEN2; LED_D5.0mm
S3: SEN3; LED_D5.0mm
S4: SEN4; LED_D5.0mm
SEN1: Sensor 1; PinHeader_1x04_P2.54mm_Vertical
SEN2: Sensor 2; PinHeader_1x04_P2.54mm_Vertical
SEN3: Sensor 3; PinHeader_1x04_P2.54mm_Vertical
SEN4: Sensor 4; PinHeader_1x04_P2.54mm_Vertical
SW1: SW; SW_PUSH-12mm_Wuerth-430476085716
TRANS1: S8050; TO-92_Inline

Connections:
+3.3V: J1.1 (3V3), J1.17 (3V3), RSW1.1, SEN1.4, SEN2.4, SEN3.4, SEN4.4
+5V: BZ1.1 (+), J1.2 (5V), J1.4 (5V), LID1.4
/Lidar: J1.33 (PWM1/GPIO13), LID1.2
/Lidar-UART: J1.10 (GPIO15/RXD), LID1.1
/SDA: J1.3 (SDA/GPIO2), SEN1.1, SEN2.1, SEN3.1, SEN4.1
/SLC: J1.5 (SCL/GPIO3), SEN1.2, SEN2.2, SEN3.2, SEN4.2
/Sensor 1: J1.19 (MOSI0/GPIO10), RLED1.1
/Sensor 2: J1.23 (SCLK0/GPIO11), RLED2.1
/Sensor 3: J1.32 (PWM0/GPIO12), RLED3.1
/Sensor 4: J1.21 (MISO0/GPIO9), RLED4.1
/buzzer: J1.38 (GPIO20/MOSI1), RBUZZ1.1
/green: J1.31 (GCLK2/GPIO6), RLED0.1
/switch: J1.29 (GCLK1/GPIO5), RSW2.1
GND: Green1.1 (K), J1.6 (GND), J1.9 (GND), J1.14 (GND), J1.20 (GND), J1.25 (GND), J1.30 (GND), J1.34 (GND), J1.39 (GND), LID1.3, S1.1 (K), S2.1 (K), S3.1 (K), S4.1 (K), SEN1.3, SEN2.3, SEN3.3, SEN4.3, SW1.1, TRANS1.1 (E)
unnamed: BZ1.2 (-), TRANS1.3 (C)
unnamed: Green1.2 (A), RLED0.2
unnamed: RSW1.2, RSW2.2, SW1.2
unnamed: RLED1.2, S1.2 (A)
unnamed: RLED2.2, S2.2 (A)
unnamed: RLED3.2, S3.2 (A)
unnamed: RLED4.2, S4.2 (A)
unnamed: RBUZZ1.2, TRANS1.2 (B)

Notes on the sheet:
MOT2 DIR
MOT1 DIR
I2S BCLK
USR BTN
LED
I2S LRCLK
I2S SDATA
RST BTN

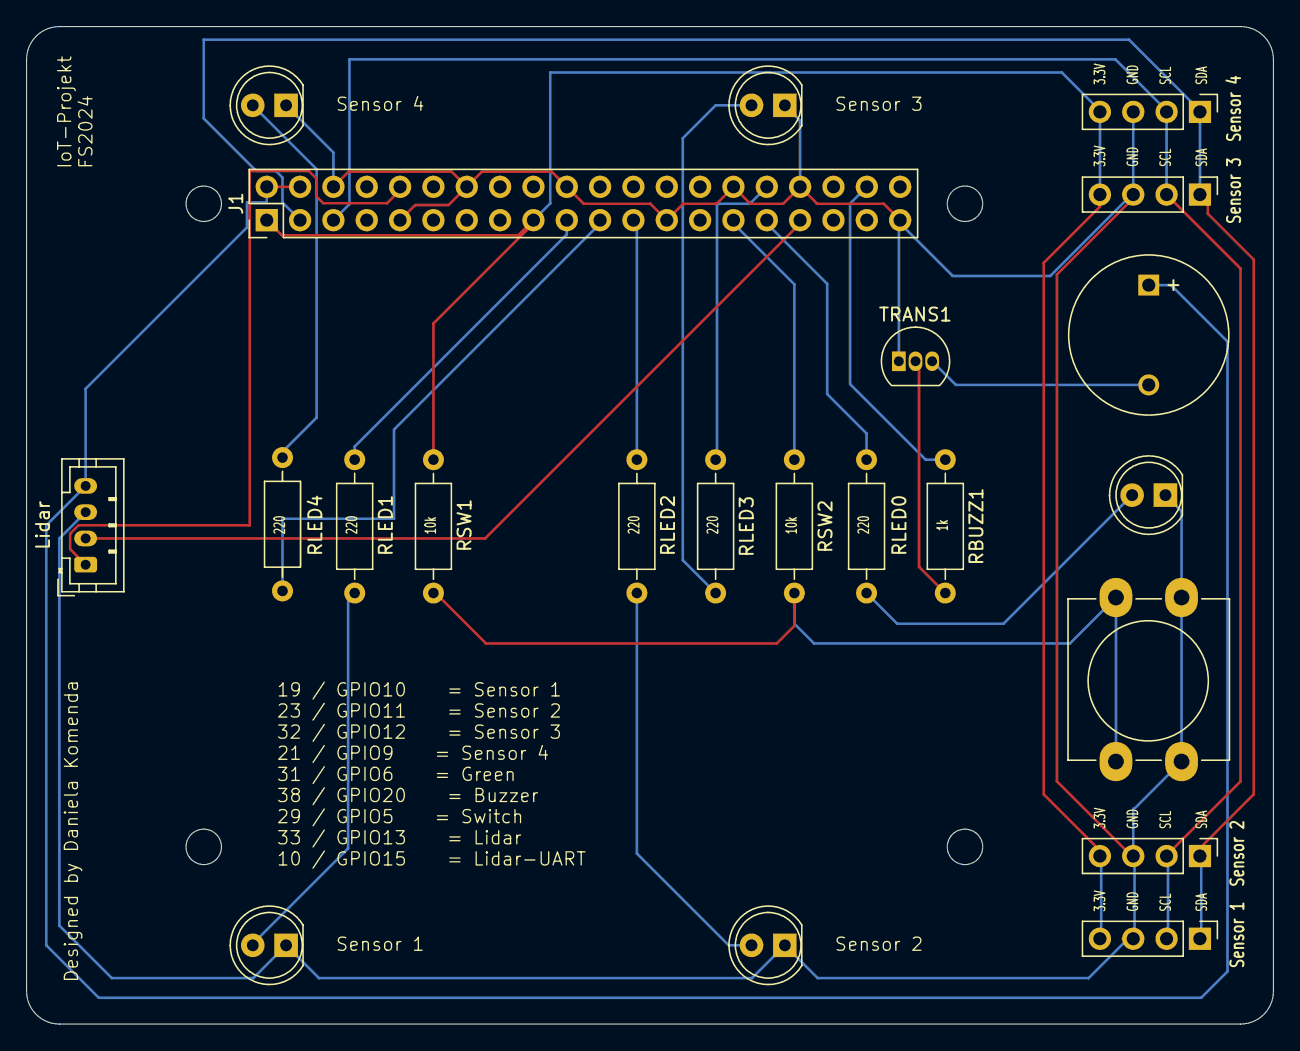
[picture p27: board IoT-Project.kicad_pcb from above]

Board: 2 copper layers, 95.0 x 76.0 mm, 26 parts (0 on the bottom side), 22 nets.

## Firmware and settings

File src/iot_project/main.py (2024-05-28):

import os

import trio

from .sunfounder_picar.picarx_control import car_control_loop
from .gas_sensors.gas_monitoring_system import MonitoringSystem


async def main():
    import dotenv

    # Load environment variables from .env file
    dotenv.load_dotenv()

    # Get MongoDB-URI
    mongo_uri = os.getenv("MONGODB_URI")

    system = MonitoringSystem(mongo_uri)

    with system:
        async with trio.open_nursery() as nursery:
            nursery.start_soon(car_control_loop)
            nursery.start_soon(system.main_task)


if __name__ == "__main__":
    trio.run(main)

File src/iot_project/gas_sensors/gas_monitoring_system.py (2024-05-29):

import datetime
import os

import trio
import anyio
import numpy as np

from .multigas_sensors import MultiGasSensor, SensorType
from .alert_handling import AlertManager
from .db_connect import connect_to_db, represent_for_mongodb

i2cbus = 1
NH3_ADDRESS = 0x75
CO_ADDRESS = 0x76
O2_ADDRESS = 0x77


class MonitoringSystem:

    def __init__(self, mongo_uri, *, measurement_interval=0.1, aggregation_interval=0.5):
        self.mongo_uri = mongo_uri
        self.alert_manager = AlertManager()
        self.measurement_interval = measurement_interval
        self.aggregation_interval = aggregation_interval
        self.sensors = dict(
            NH3=MultiGasSensor(i2cbus, NH3_ADDRESS, SensorType.NH3),
            CO=MultiGasSensor(i2cbus, CO_ADDRESS, SensorType.CO),
            O2=MultiGasSensor(i2cbus, O2_ADDRESS, SensorType.O2),
        )


    async def main_task(self):
        async with trio.open_nursery() as nursery:
            nursery.start_soon(self.alert_manager.alert_loop)
            nursery.start_soon(self.measurement_loop)


    def __enter__(self):
        self.alert_manager.__enter__()


    def __exit__(self, type, value, tb):
        return self.alert_manager.__exit__(type, value, tb)


    def aggregate_data(self, alldata: list[tuple[float, float]]) -> dict[str, float]: # tuple(time, data)        
        if not alldata:
            # Sensor seems to be failing for the whole Aggregation-Intervall (no data)
            aggregation = dict(
                min=None,
                max=None,
                avg=None,
            )

        else:
            data = np.array([data for time, data in alldata])

            min = data.min()
            max = data.max()
            avg = data.mean()

            aggregation = dict(
                min=min,
                max=max,
                avg=avg,
            )

        return aggregation


    async def measurement_loop(self):

        next_measurement = trio.current_time() + self.measurement_interval
        next_aggregation = trio.current_time() + self.aggregation_interval

        with connect_to_db(self.mongo_uri) as collection:

            while True:
                all_data = {k: [] for k in self.sensors}
                time = None
                data = {}
                
                while trio.current_time() < next_aggregation:                    
                    time = (
                        datetime.datetime.now()
                        .astimezone(None)
                        .astimezone(datetime.timezone.utc)
                    )
                    
                    for k, v in self.sensors.items():
                        if k in data:
                            # If some Sensors fail, there is a re-try. If k is in data, then this Sensor was already successful
                            continue
                        try:
                            result = v.read_all().gas_concentration
                        except Exception as ex:
                            #print(f'{ex!r} - retry')
                            continue
                        
                        data[k] = result
                        all_data[k].append((time, result))
                        self.alert_manager.check_alerts(
                            **{k.lower(): result}
                        )

                    if len(data) < len(self.sensors):
                        # If not all Sensors have data, there is a re-try after 0.05 seconds
                        await trio.sleep(0.05)
                        continue


                    # If there are data from all the sensors, we wait until the next measurement
                    await anyio.sleep_until(next_measurement)
                    next_measurement += self.measurement_interval
                    
                    # Empty the Data-Set, so all Sensors are measured again
                    data = {}

                # Aggregate Data
                next_aggregation += self.aggregation_interval
                aggregation = {k: self.aggregate_data(v) for k, v in all_data.items()}
                aggregation.update(time=time)
                
                if any(v is None for v in aggregation.values()):
                    print(f"Sensor-Problem: {aggregation}")
                collection.insert_one(represent_for_mongodb(aggregation))

                print(aggregation)


async def main():
    import dotenv

    # Load environment variables from .env file
    dotenv.load_dotenv()

    # Get MongoDB-URI
    mongo_uri = os.getenv("MONGODB_URI")

    system = MonitoringSystem(mongo_uri)

    with system:
        await system.main_task()


if __name__ == "__main__":
    trio.run(main)

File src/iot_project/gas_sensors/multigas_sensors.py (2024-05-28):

import enum
import time
import dataclasses
import struct
import math
import binascii

import smbus


class CmdCode(enum.Enum):
    read_concentration = 0x86
    read_temp = 0x87
    read_all = 0x88


class SensorType(enum.Enum):
    O2 = 0x05
    CO = 0x04
    H2S = 0x03
    NO2 = 0x2C
    O3 = 0x2A
    CL2 = 0x31
    NH3 = 0x02
    H2 = 0x06
    HCL = 0x2E
    SO2 = 0x2B
    HF = 0x33
    PH3 = 0x45


@dataclasses.dataclass
class SensorData:
    gas_concentration: float  # ppm
    sensor_type: SensorType
    temperature: float  # degree Celsius


class MultiGasSensor:
    """
    Class for all Gas-Sensors
    Adapted from https://github.com/DFRobot/DFRobot_MultiGasSensor
    """

    def __init__(
        self,
        bus_number: int,
        i2c_address: int,
        expected_sensor_type: SensorType | None = None,
    ):
        self.i2c_bus = smbus.SMBus(bus_number)
        self.i2c_address = i2c_address
        self.expected_sensor_type = expected_sensor_type


    @classmethod
    def calc_check_sum(cls, data: bytes) -> int:
        return (~sum(data) + 1) & 0xFF


    def command(self, code: CmdCode, *args: bytes) -> bytes:
        data = bytes([0xFF, 0x01, code.value]) + b"".join(args)
        data += b"\x00" * (8 - len(data))
        data += bytes([self.calc_check_sum(data[1:-1])])
        self.i2c_bus.write_i2c_block_data(self.i2c_address, 0, list(data))
        time.sleep(0.1)  # TO-DO: async-sleep machen

        result = self.i2c_bus.read_i2c_block_data(self.i2c_address, 0, 9)
        result = bytes(result)
        result_str = binascii.hexlify(result, " ", 1)

        assert result[0] == 0xFF, result_str
        assert result[1] == code.value, result_str
        assert result[8] == self.calc_check_sum(
            result[1:-2]
        ), f"CRC failure: received 0x{result[8]:02x}, calculated 0x{self.calc_check_sum(result[1:-1]):02x}, ({result_str})"

        return result[2:-1]


    def read_all(self) -> SensorData:
        result = self.command(CmdCode.read_all)

        # '>': big-endian encoded struct (MSB first: most significant byte first);
        # 'H': 2 Bytes unsigned integer ("half long integer")
        # 'B': 1 Byte unsigned integer  ("byte")
        gas_concentration_raw, sensor_type, decimal_places, temperature_raw = (
            struct.unpack(">HBBH", result)
        )
        gas_concentration = gas_concentration_raw * 10**-decimal_places
        sensor_type = SensorType(sensor_type)

        Vpd3 = 3 * temperature_raw / 1024  # Spannung in Volt
        Rth = (
            Vpd3 * 10000 / (3 - Vpd3)
        )  # Spannung mit Spannnungsteiler vonem 10k-Widerstand
        temperature = (
            1 / (1 / (273.15 + 25) + 1 / 3380.13 * (math.log(Rth / 10000))) - 273.15
        )  # Transfer-Kurve von temperaturfühler mit 10kOhm bei 25°C und alpha-Wert von 3380.13

        if self.expected_sensor_type is not None:
            assert sensor_type == self.expected_sensor_type

        return SensorData(
            gas_concentration=gas_concentration,
            sensor_type=sensor_type,
            temperature=temperature,
        )

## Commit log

2024-03-25 Started implementing Button
2024-04-08 MultiGas-Sensor-ohne Cloud implemented
2024-04-08 MultiGas-Sensor-mitCloud: started implementing
2024-04-08 bug fixes in MultiGas-Sensor-ohneCloud
2024-05-13 add flow which is working
2024-05-13 add other flow
2024-05-25 started with Python-Script
    [IoT-Project.kicad_pcb, IoT-Project.kicad_sch]
2024-05-25 refactoring sensor-software
2024-05-25 adding message flow
2024-05-25 uploading seperate dashboard flow
2024-05-26 Weiterarbeit an der Präsentation
2024-05-28 Changes in the gas_monitoring_system and Board-Tests
    [Board-Tests.xlsx]
2024-05-28 Vorbereitung für finale Abgabe
    [IoT-Project-B_Cu.gbr, IoT-Project-B_Mask.gbr, IoT-Project-Edge_Cuts.gbr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]
2024-05-29 adding new flows
2024-05-29 new flow
2024-05-29 Änderungen in der Präsentation
2024-05-31 adding mail flow
2024-06-03 Präsentation für die Abgabe
